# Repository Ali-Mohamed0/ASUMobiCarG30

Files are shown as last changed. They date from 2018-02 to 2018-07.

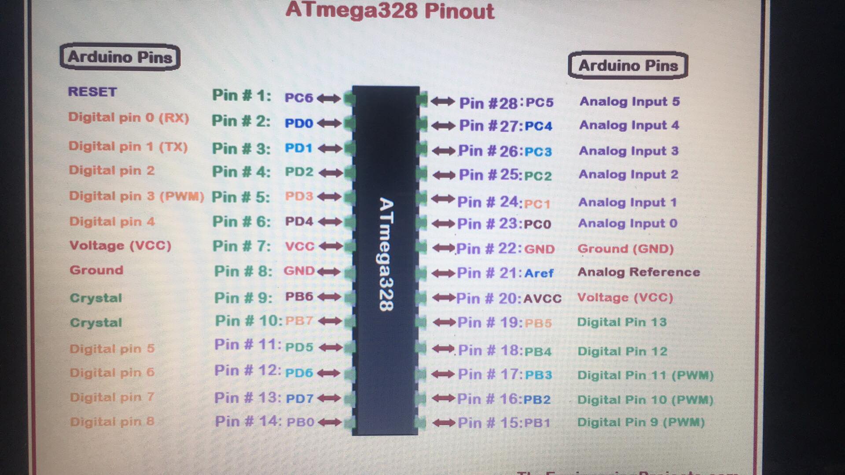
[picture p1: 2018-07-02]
AVR examples & data sheet/AVR pins VS Arduino pins.jpg

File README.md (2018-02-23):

# ASUMobiCarG30
## Smart toy car

smart toy project

This is Project is made by a group of students from Faculty of Engineering AinShams University Electrical engineering department 2nd year Starting by 10/2/2018 till 10/5/2018.

                   Under Supervision of :  Dr Muhammad Sobh

### Smart Car Features Description :

This is an featured RC-Car which have additional skills and options to perform nontraditional missions 

### Easy Driving Application.

  User can control the car Movements Forward ,right..etc, by using an easy mobile app. or by Desktop app. even a 
     child can use it. 
     
  The Car can avoid obstacles under minimum conditions . 

### Line Tracking Application.

   Provide line tracking mode by following a black track on a white background.

### Accurate Movement Application. 

  Provide accurate movement driving mode.
  
  Can move in rectangular shaped path or circle path according to a certain movement distance and angle.
  
### Maximizes the all abilities as possible as can.

  Maximum battery capacity.
  
  Maximum speed.

###  Team Members :                    

#### 1-Ali Mohamed

#### 2-Mayar Gamal

#### 3-Mai Mohsen

#### 4-Ali Ahmed

#### 5-Abdallh Mohamed

#### 6-Sara Krm

#### 7-Omar Abd EL Shafy

#### 8-Mayar Sayed

#### 9-Abdelazim Mohamed

#### 10-Omar Ahmed

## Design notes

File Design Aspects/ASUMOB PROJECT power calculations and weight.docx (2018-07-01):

ASUMOB PROJECT

-This document will show the estimated power calculations ,weight , Expected speed and acceleration of the line follower Robot.

1) Robot Weight:

The estimation of robot weight is between 0.6 kg to 0.8 kg , based on the estimated weight of the chassis and the components :

Note : Fixation weight is included .

-Chassis:

the base of the robot will be a sheet of wood which nearly weighs 0.1 kg .

-Batteries:

6 cells of lithium ion batteries weigh approximately = 0.2 Kg

-Sensors and Pcb :

Approx. 0.2Kg
-motors

2 motors each 0.1 kg

And two tires with 0.08 Kg

2) Torque and power Calculations :

Note: the weight used in all calculations is 0.8 Kg

-Motor power :
we are using two motors each has 250 max RPM and 3 KG.Cm Torque .

Pout “The output power of each motor” = TxW=7.6 Watt

T:torque in N.M

W:angular speed in Rad/sec

-we are targeting a max speed reach in the first second of operation The max speed = RPM x D X Pi /60 =0.9 m/s

D: diameter of the tire

-so the Torque required to achieve 1 m/s acceleration is for each tire calculated by :

T= R x M(For *g+ acc)=0.13 N.M =1.3Kg.cm

For : rolling resistance force , approx. = 0.02 N

M:mass of robot

R:radius of tire

-Since the input power of one motor = IV , also Pin=Pout

Then IV=TW

Using this relation and considering the angular speed is max and the operating voltage is 6 V the current drawn by the motor can be calculated , this is being done as the motor is old and we don’t have a datasheet for it so this is just an estimation

I=TW/V = 0.13x26/6=0.5 Ampere

NOTE : this equation and calculation hasn’t been validated and this is a absolutely an approximation and we are neglecting many factors

As noticed from the equation the relation is linear between the current and the Torque needed ,shown by this graph

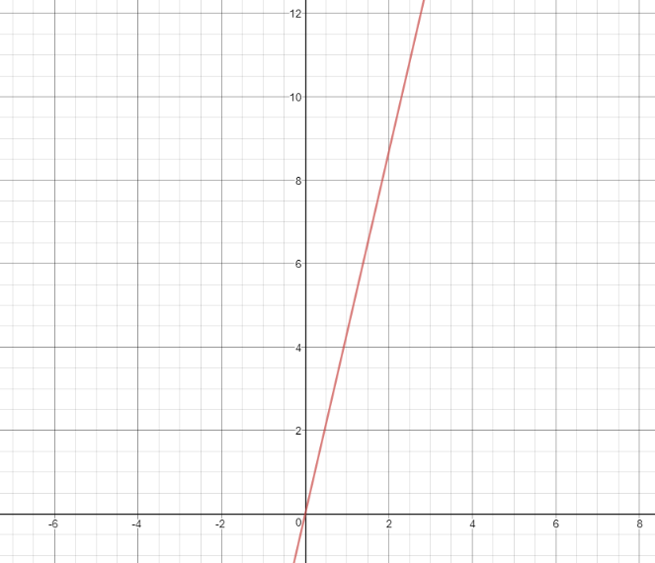
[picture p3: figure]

-Y-axis is I , X-axis is torque

Since Torque = R(For*g+acc) Mass

There is also aan approx. linear relation between Torque and mass , so by substituting in current torque equation ,

I=(WR(For*g+acc) /V)* MASS

The relation is showed by this graph

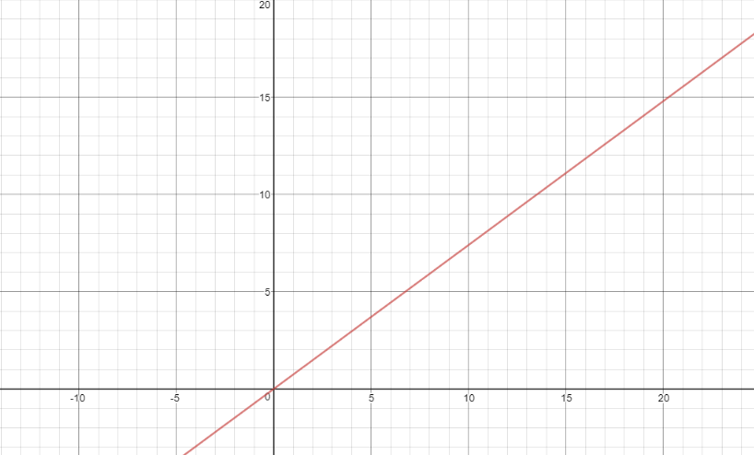
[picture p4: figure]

Y-axis : current

X-axis : mass

By using this graph and relation we can see if adding more batteries will give as advantage or will increase the energy used so we can compromise .

NOTE :this graph and relations has been done manually and not revised or validated this is an approximation which could be wrong .

References :

Graphing calculator :

https://www.desmos.com/calculator

Unit conversions :

-https://www.convertunits.com/from/N-cm/to/kg-cm

-https://www.convertunits.com/from/RPM/to/rad/sec

Equations :

-https://www.physicsforums.com/threads/robot-design-torque-required.512898/

-http://simplemotor.com/calculations/

- https://www.micromo.com/technical-library/dc-motor-tutorials/motor-calculations

- http://www.tribology-abc.com/calculators/cycling.htm

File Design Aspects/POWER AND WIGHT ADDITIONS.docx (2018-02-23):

POWER AND WIGHT ADDITIONS

POWER :

WEIGHT :

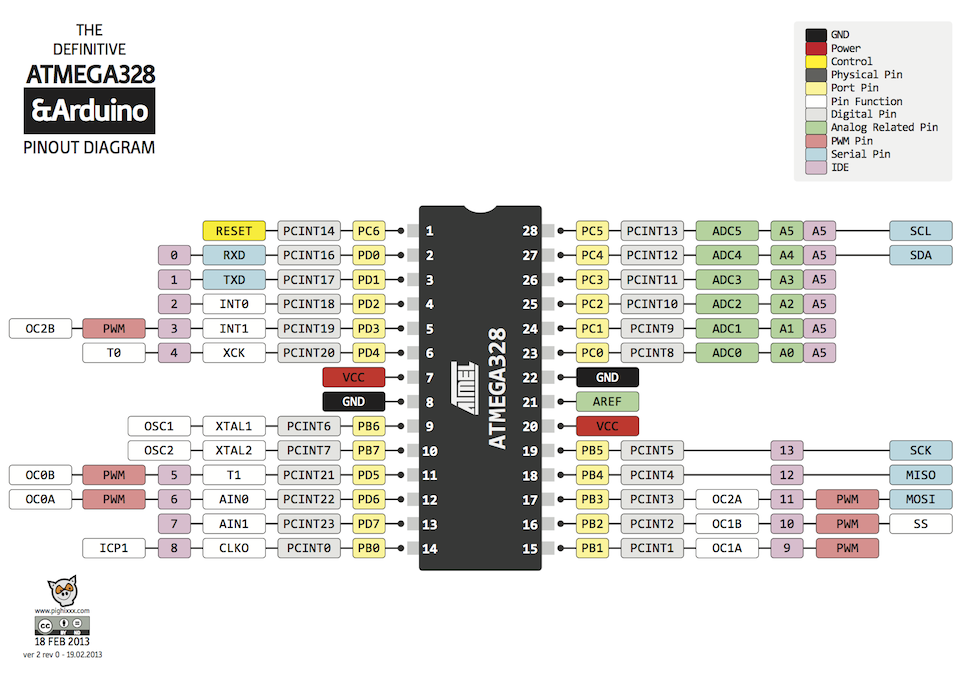
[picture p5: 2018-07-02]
AVR examples & data sheet/ATmega328_pinout_diagram.png

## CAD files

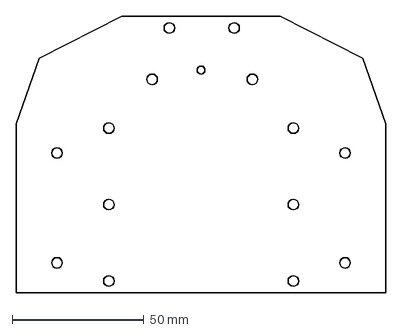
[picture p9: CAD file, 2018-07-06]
Design Simulations/line follower small modified design/final design DXF files/main body.dxf
140.0 x 104.7 mm

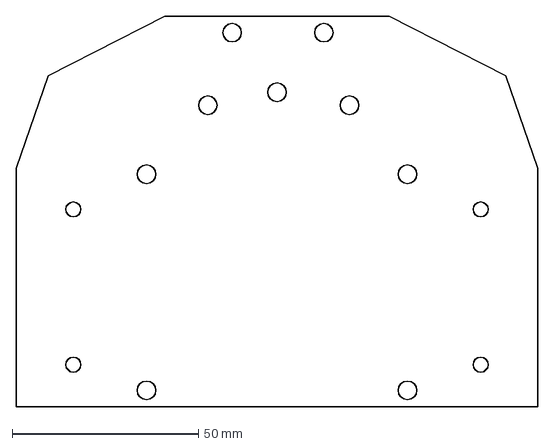
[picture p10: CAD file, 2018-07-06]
Design Simulations/line follower small modified design/final DXF files 5 mm holes/main body.dxf
140.0 x 104.7 mm

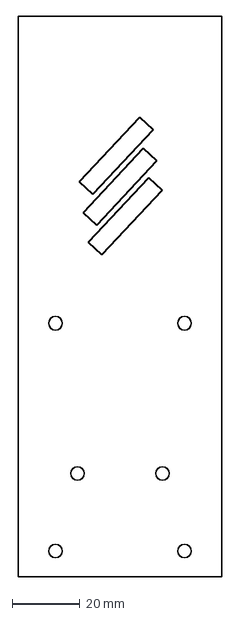
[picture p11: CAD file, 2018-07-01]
Design Simulations/initial design/DXF files/ARM 6mm FINAL with good shape.dxf
60.0 x 165.0 mm

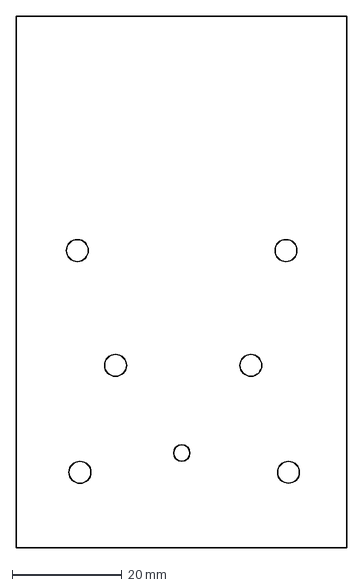
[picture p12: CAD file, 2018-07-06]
Design Simulations/line follower small modified design/final design DXF files/ARM.dxf
60.2 x 96.8 mm

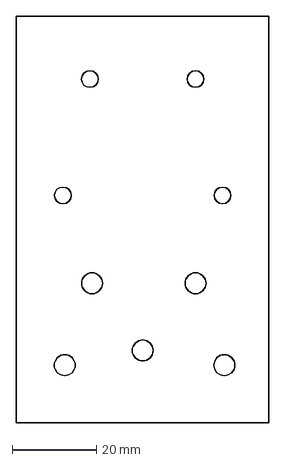
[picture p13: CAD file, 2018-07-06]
Design Simulations/line follower small modified design/final DXF files 5 mm holes/arm.dxf
60.2 x 96.8 mm

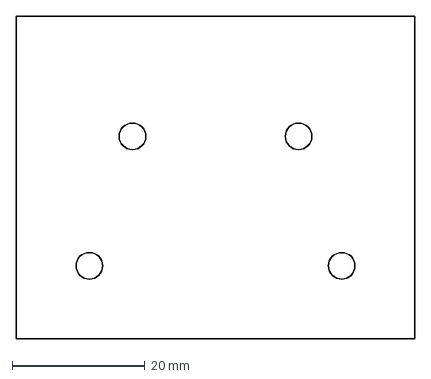
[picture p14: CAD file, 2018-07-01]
Design Simulations/initial design/DXF files/arm support 3mm.dxf
60.0 x 48.5 mm

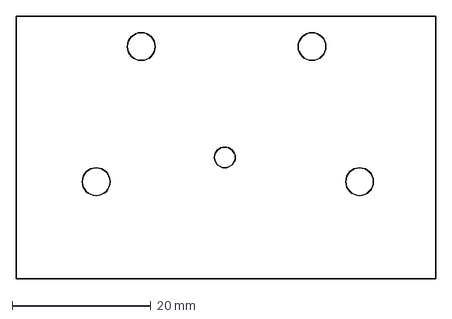
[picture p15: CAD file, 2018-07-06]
Design Simulations/line follower small modified design/final design DXF files/distance supporting part.dxf
60.5 x 37.9 mm

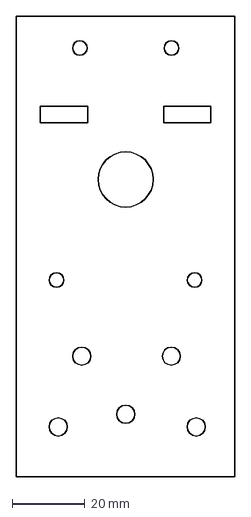
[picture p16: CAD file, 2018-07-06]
Design Simulations/line follower small modified design/final DXF files 5 mm holes/arm final.dxf
60.2 x 126.8 mm

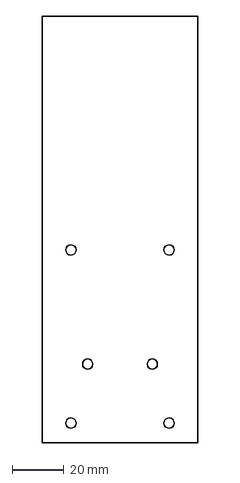
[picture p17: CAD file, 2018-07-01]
Design Simulations/initial design/DXF files/ARM EXTENSION 6 mm FINAL.dxf
60.0 x 165.0 mm

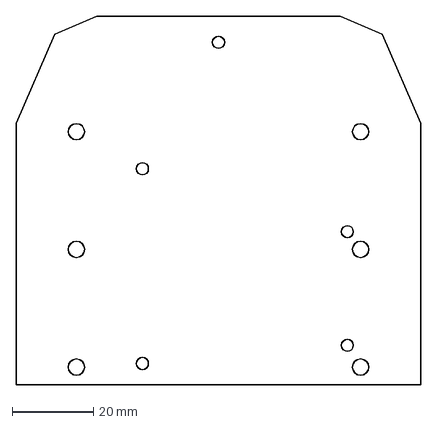
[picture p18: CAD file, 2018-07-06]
Design Simulations/line follower small modified design/final design DXF files/Roof.dxf
99.7 x 90.8 mm

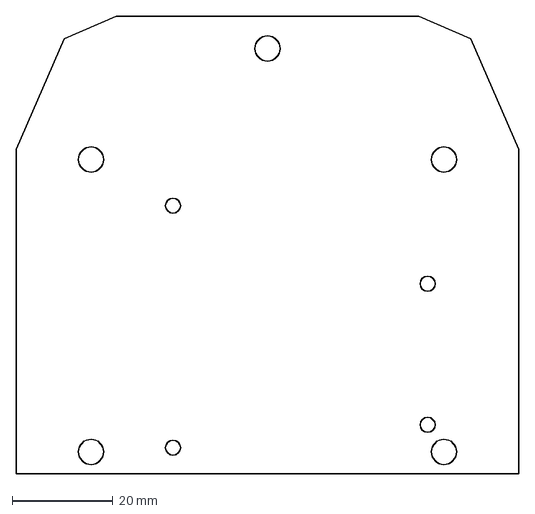
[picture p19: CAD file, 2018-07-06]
Design Simulations/line follower small modified design/final DXF files 5 mm holes/Roof.dxf
99.7 x 90.8 mm

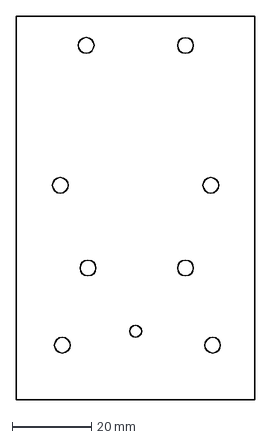
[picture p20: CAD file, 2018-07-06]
Design Simulations/line follower small modified design/final design DXF files/ARM 2.dxf
60.2 x 96.8 mm

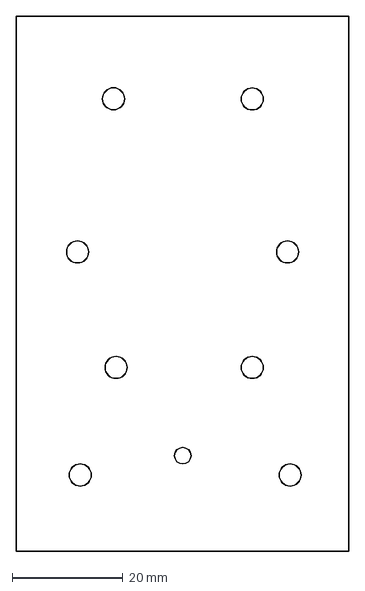
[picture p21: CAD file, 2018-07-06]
Design Simulations/line follower small modified design/final design DXF files/ARM FINAL , WITH IR HOLES.dxf
60.2 x 96.8 mm

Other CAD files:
Design Simulations/initial design/ARM extension 6 mm with drawing.ipt
Design Simulations/initial design/ARM extension 6 mm.ipt
Design Simulations/initial design/car body MAIN PART.ipt
Design Simulations/line follower small modified design/OldVersions/final design with enough battery rooms.0005.ipt
Design Simulations/line follower small modified design/final design with enough battery rooms - Copy.ipt
Design Simulations/line follower small modified design/final design with enough battery rooms.ipt
Design Simulations/line follower small modified design/final design with middle sensor space.ipt
Design Simulations/line follower small modified design/finalll designn small one without arduino boundries.ipt

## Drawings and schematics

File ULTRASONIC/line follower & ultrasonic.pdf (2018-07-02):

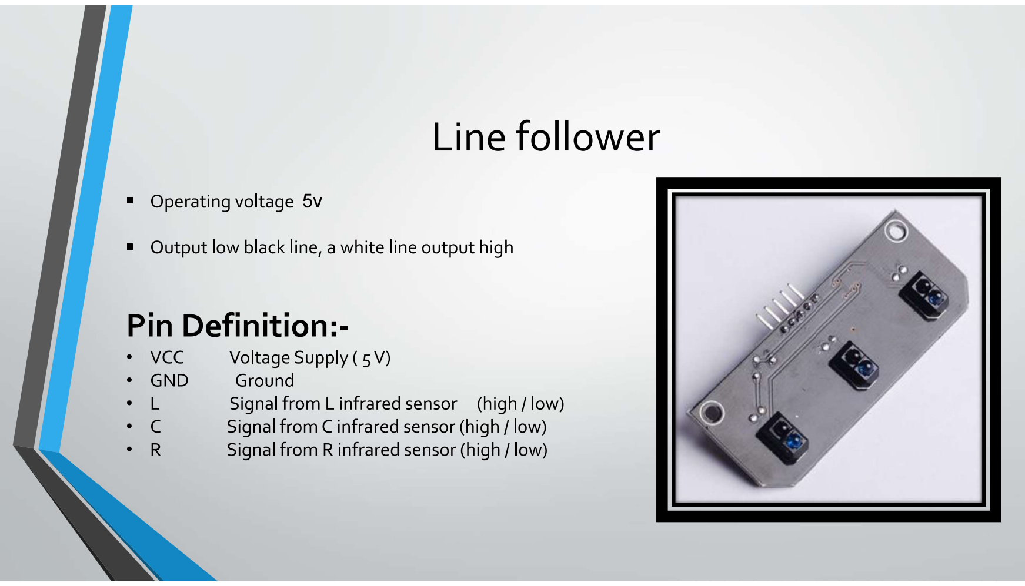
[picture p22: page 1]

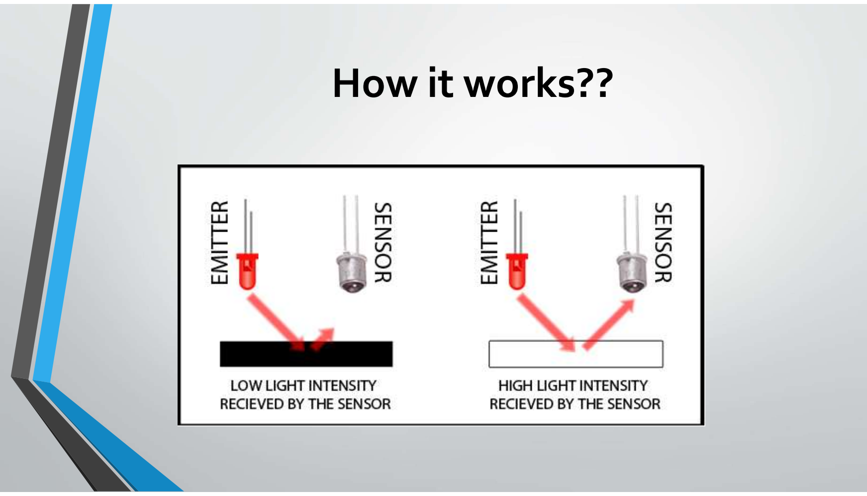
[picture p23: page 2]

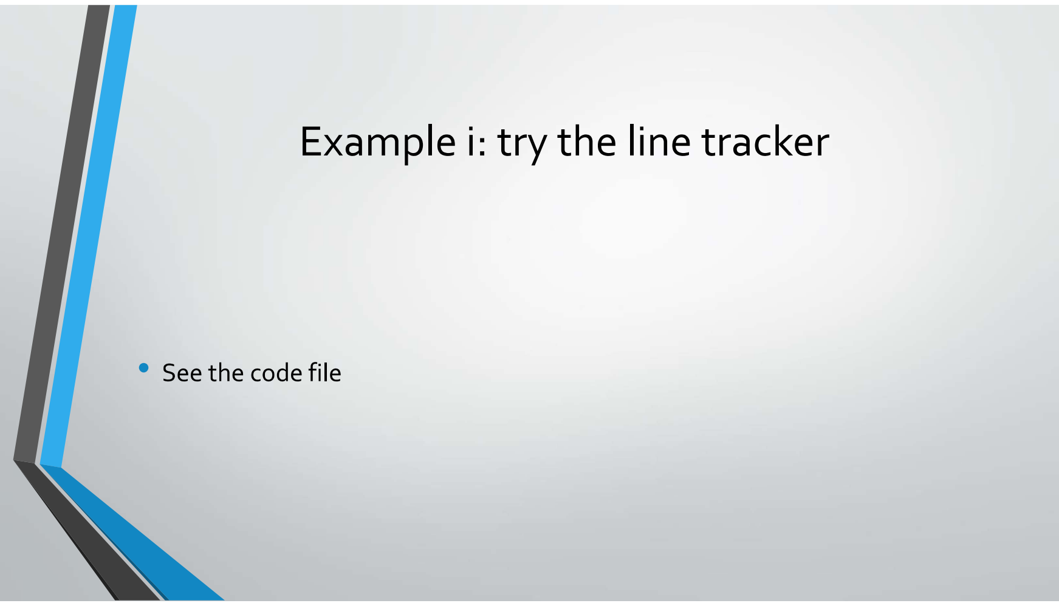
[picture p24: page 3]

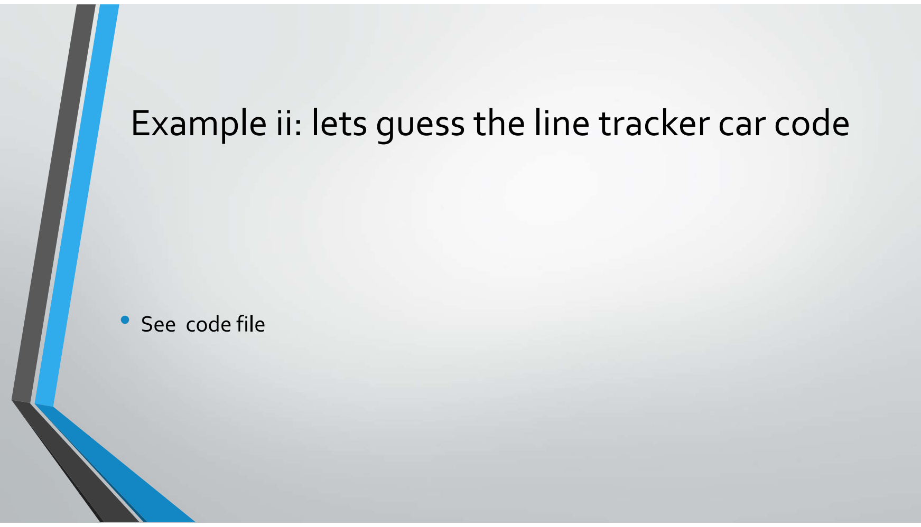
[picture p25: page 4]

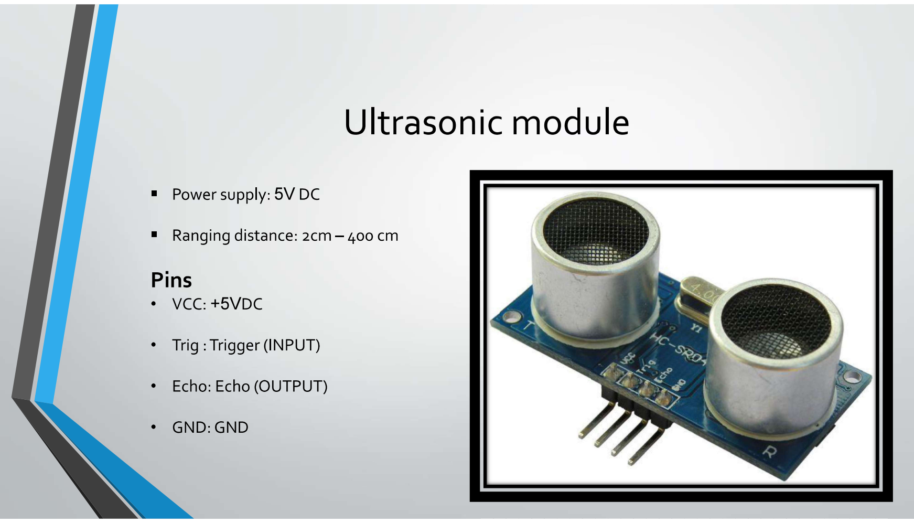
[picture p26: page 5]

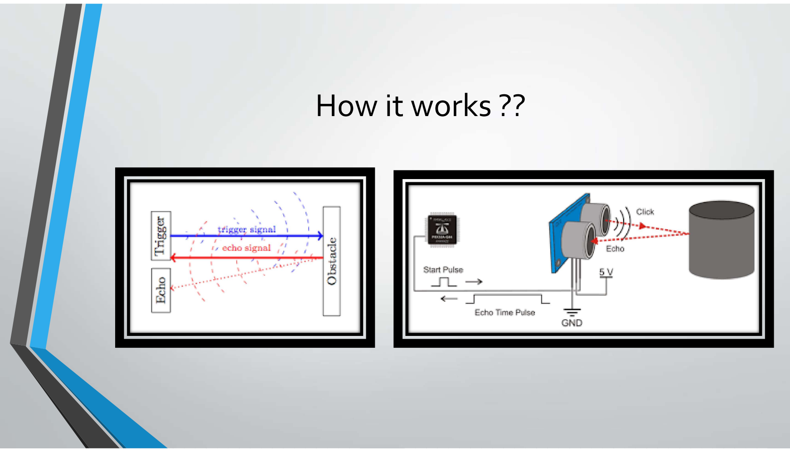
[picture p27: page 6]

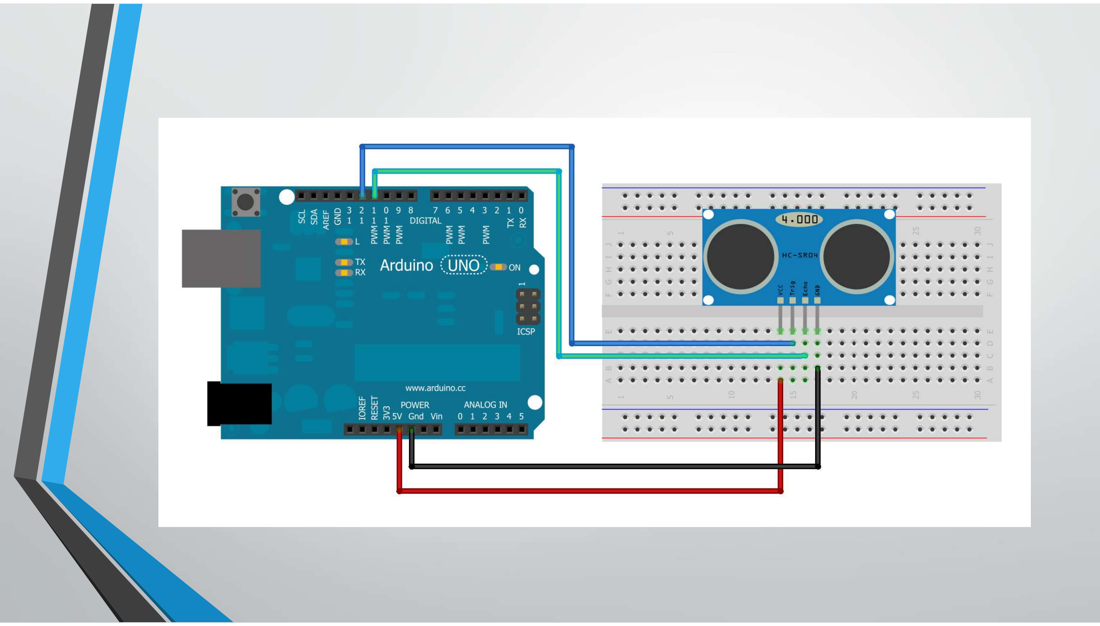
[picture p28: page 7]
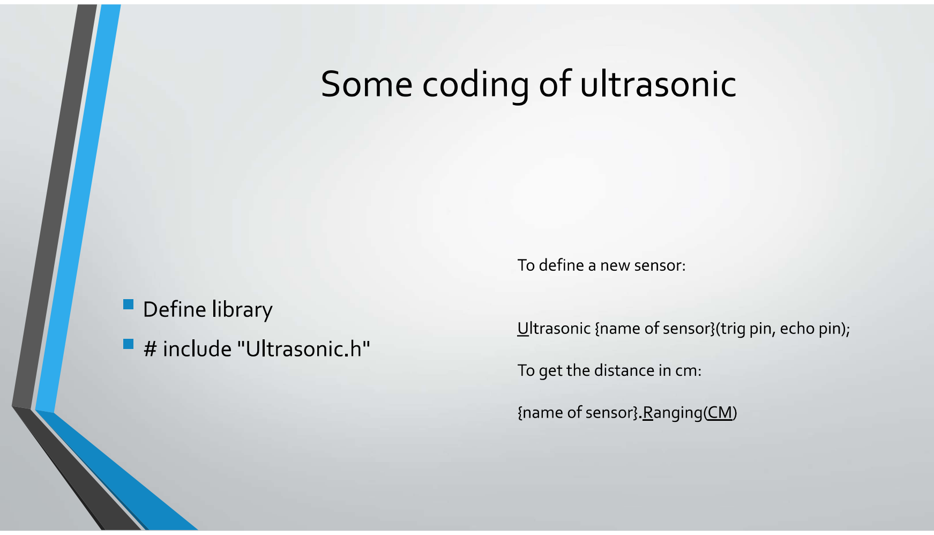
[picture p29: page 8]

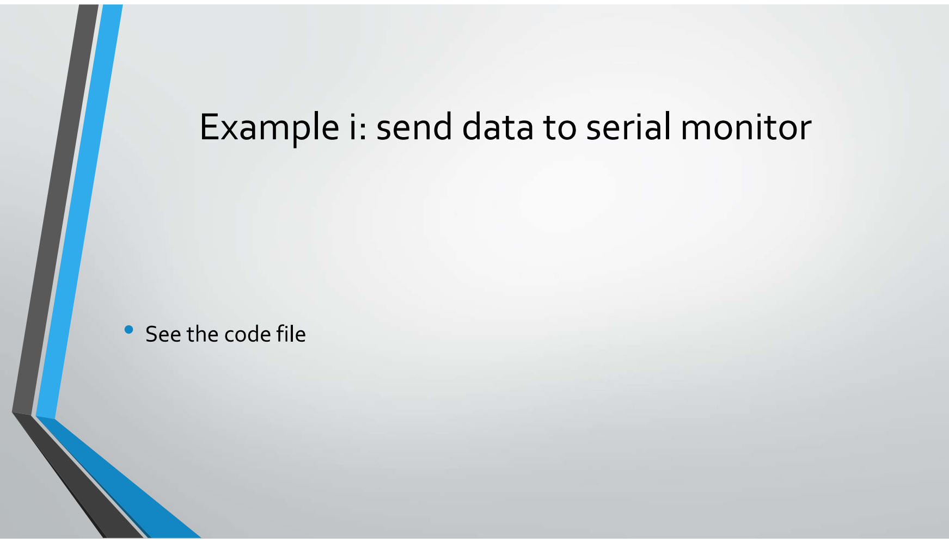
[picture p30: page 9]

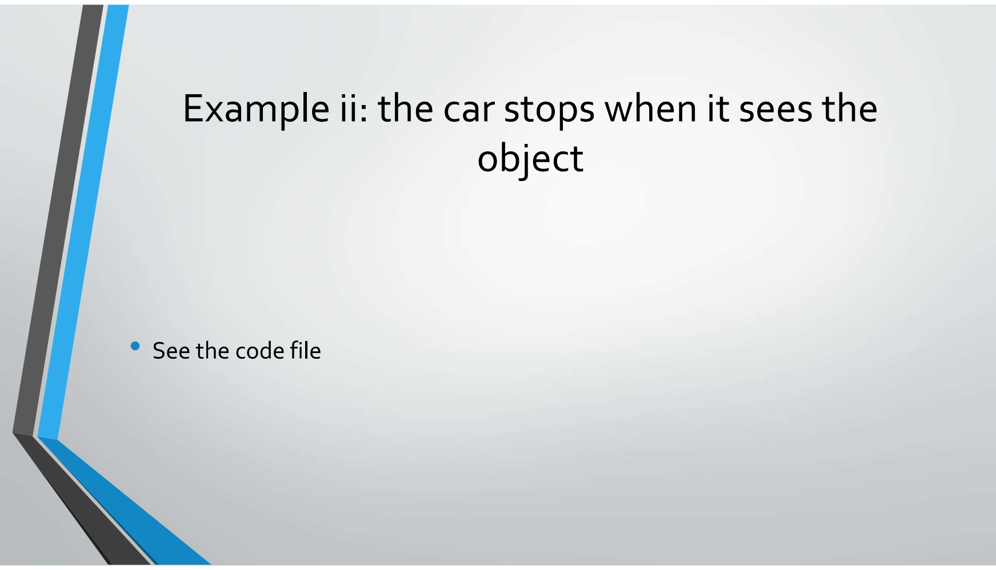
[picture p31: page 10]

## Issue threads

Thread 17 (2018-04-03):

‎problem considering the design frame

Abdallh-Mohamed96, 2018-04-03:

Closed 2018-07-06.

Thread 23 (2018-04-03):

problem solved and design cut

Abdallh-Mohamed96, 2018-04-03:

Abdallh-Mohamed96, 2018-04-21:
modification is in progress

Closed 2018-04-21.

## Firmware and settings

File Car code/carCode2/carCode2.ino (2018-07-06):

int m1f=2;
int m1b=4;
int m1e=5;
int m2f=8;
int m2b=12;
int m2e=6;

int r=0;
int l=0;
int c=1;
int sen3=5;
//line follower
int LeftSen= 3;
int RightSen=13;
int CenterSen= 9 ; 
void forward(int velocity );
void forwardright(int velocity );
void forwardleft(int velocity );
void backward(int velocity);
void right(int velocity);
void left(int velocity);
void stopcar();
void ultrasonic();
void linefollower();
int readLongNum();
void displacement(int dist);
void angle(int ang);
void rect();
void circ();
void inf();
void drawShapes();

//for ultrasonic
const int trigPin = 11;     // defines pins numbers
const int echoPin = 10;
char ultra='u';

int delPercm=60;
int delPerang=10;
float speedratio=2;
int circuleDelay=2500;

char re;
long duration, cm;
long microsecondsToCentimeters(long microseconds)
{
  return microseconds / 29 / 2 ;
}

//........................
int velocity;
void setup() {
  delay(10);
  pinMode(m1f, OUTPUT);
  pinMode(m1b, OUTPUT);
  pinMode(m1e, OUTPUT);
  pinMode(m2f, OUTPUT);
  pinMode(m2b, OUTPUT);
  pinMode(m2e, OUTPUT);

  //line follower
  pinMode(LeftSen,INPUT); 
  pinMode(RightSen,INPUT);
  pinMode(CenterSen,INPUT);
 
  //for Ultrasonic
 pinMode(trigPin, OUTPUT);     // Sets the trigPin as an Output
 pinMode(echoPin, INPUT);     // Sets the echoPin as an Input
 
 Serial.begin(9600);         // Starts the serial communication
}

void loop() {
  delay(50);
  if(Serial.available()){
      re=Serial.read();  

  if ( re == '1' ){
    velocity = 0;
  }else if ( re == '2' ){
    velocity = 100;
  }else if (re == '3' ){
    velocity = 200;
  }else if (re == '4' ){
    velocity = 254;
  }


 
    }
    if(re=='F'){forward( velocity);}
    if(re=='B'){backward( velocity);}
    if(re=='R'){right( velocity);}
    if(re=='L'){left( velocity); }
    if(re=='S'){stopcar();}
    if(re=='A'){linefollower();}
    if(re=='U'){ultra='U';}
    if(re=='u'){ultra='u';}
    if(re=='D'){displacement(readLongNum());re='e';}
    if(re=='G'){angle(readLongNum());re='e';}
    if(re=='T'){velocity=readLongNum();re='e';}
    if(re=='d'){delPercm=readLongNum();re='e';}
    if(re=='a'){delPerang=readLongNum();re='e';}
    if(re=='r'){speedratio=readLongNum()/100.0;re='e';}
    if(re=='c'){circuleDelay=readLongNum();re='e';}
    if(re=='h'){drawShapes();re='e';}
    if(re=='o'){rect();re='e';}
    if(re=='p'){circ();re='e';}
    if(re=='q'){inf();re='e';}
    //Serial.println(speedratio);
    if(ultra=='U'){
      ultrasonic();
    }
    
          
}
/*line folower*/
 void linefollower(){ 
  r=digitalRead(RightSen);
  c=digitalRead(CenterSen);
  l=digitalRead(LeftSen);
  
  if (!l & c & !r)
  {
    forward(velocity);
  }

  else if(!l & !c & r )
  {
    right(velocity);
  }
  else if(l & !c & !r)
  {
    left(velocity);
  }
 
} 

  /*****************************/
void ultrasonic(){
  delay(100);
  digitalWrite(trigPin, LOW);       // Clears the trigPin
  delayMicroseconds(2);
  digitalWrite(trigPin, HIGH);       // Sets the trigPin on HIGH state for 10 micro seconds
  delayMicroseconds(10);
  digitalWrite(trigPin, LOW);

  duration = pulseIn(echoPin, HIGH);    // Reads the echoPin, returns the sound wave travel time in microseconds
 
   cm = microsecondsToCentimeters(duration);
  //Serial.print(cm);
  //Serial.print("cm");
               

     if(cm<30) 
  {
    stopcar();
    delay(1000);
    backward(velocity);
    delay(500);
    left(velocity);   // turn left
    delay(700);
    stopcar();
  }
  
  } 

void forward(int velocity){
    
  analogWrite(m1e, velocity);
  analogWrite(m2e, velocity);
  digitalWrite(m1f, HIGH);
  digitalWrite(m2f, HIGH);
  digitalWrite(m1b, LOW);
  digitalWrite(m2b, LOW);
  }
  void forwardright(int velocity ){
  analogWrite(m1e, velocity*speedratio);
  analogWrite(m2e, velocity);
  digitalWrite(m1f, HIGH);
  digitalWrite(m2f, HIGH);
  digitalWrite(m1b, LOW);
  digitalWrite(m2b, LOW);
  }
void forwardleft(int velocity ){
   analogWrite(m1e, velocity);
  analogWrite(m2e, velocity*speedratio);
  digitalWrite(m1f, HIGH);
  digitalWrite(m2f, HIGH);
  digitalWrite(m1b, LOW);
  digitalWrite(m2b, LOW);
}
void backward(int velocity){
  analogWrite(m1e, velocity);
  analogWrite(m2e, velocity);
  digitalWrite(m1f, LOW);
  digitalWrite(m2f, LOW);
  digitalWrite(m1b, HIGH);
  digitalWrite(m2b, HIGH);
  
  }

  
void right(int velocity){
  analogWrite(m1e, velocity);
  analogWrite(m2e, velocity);
  digitalWrite(m1f, LOW);
  digitalWrite(m2f, HIGH);
  digitalWrite(m1b, LOW);
  digitalWrite(m2b, LOW);
  }
  
void left(int velocity){
  analogWrite(m1e, velocity);
  analogWrite(m2e, velocity);
  digitalWrite(m1f, HIGH);
  digitalWrite(m2f, LOW);
  digitalWrite(m1b, LOW);
  digitalWrite(m2b, LOW);
  }
  
void stopcar(){
  analogWrite(m1e, velocity);
  analogWrite(m2e, velocity);
  digitalWrite(m1f, LOW);
  digitalWrite(m2f, LOW);
  digitalWrite(m1b, LOW);
  digitalWrite(m2b, LOW);  
  }

  int readLongNum(){
  int NumLen;
  int tempNum;
  int rightNum=0;
  int i;
  int sflag=1;
 
  while(1){
    if(Serial.available()){
      if(sflag==1){
        NumLen=Serial.read();
        i=NumLen-'0';
        sflag=0;
      }else{
        tempNum=Serial.read();
        i--;
      
        if(tempNum=='q')break;
        else {
          tempNum=tempNum - '0';
          rightNum+=tempNum*pow(10,i);
        }
      }
    }
  }

return rightNum;
  
}
void displacement(int dist){
  forward( velocity);
  delay(dist*delPercm);
  stopcar();
}
void angle(int ang){
  left(velocity);
  delay(ang*delPerang);
  stopcar();
}
void rect(){
  displacement(100);
  angle(90);
  displacement(100);
  angle(90);
  displacement(100);
  angle(90);
  displacement(100);
  angle(90);
}
void circ(){
  forwardleft(velocity);
  delay(circuleDelay);
  stopcar();
}
void inf(){
   forwardleft(velocity);
  delay(circuleDelay);
  forwardright(velocity);
  delay(circuleDelay);
  stopcar();
}
void drawShapes(){
  rect();
  delay(10000);
  circ();
  delay(10000);
  inf();
}

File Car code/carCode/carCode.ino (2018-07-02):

#include <avr/io.h>
#include <util/delay.h>
int sen1=3;
int sen2=7;
int sen3=5;
int LeftSen= 1;
int RightSen=1;
int Center= 1 ;
void forward(int velocity );
void backward(int velocity);
void right(int velocity);
void left(int velocity);
void stopcar();
void inc_speed();
void dec_speed();
void ultrasonic();
void linefollower();

//for ultrasonic
const int trigPin = 11;     // defines pins numbers
const int echoPin = 10;
const int vcc = 7 ;
char re;
long duration, cm;
long microsecondsToCentimeters(long microseconds)
{
  return microseconds / 29 / 2 ;
}

//........................
int velocity;
void setup() {
  DDRB |= 1 << PINB1;  //setting B1 as an output
  DDRD |= 1 << PIND2;  //setting D2 as an output
  DDRD |= 1 << PIND4;  //setting D4 as an output
  DDRD |= 1 << PIND6;  //setting D6 as an output
  DDRB |= 1 << PINB0;  // setting B0 as an output
  DDRB |= 1 << PINB4;  // setting B4 as an output

  //line follower
    pinMode(sen1,INPUT); 
   pinMode(sen2,INPUT);
     pinMode(sen3,INPUT);
   /*..............*/

  //---setting fast pwm mode bits on TC0 Control Register A ---// 
    TCCR0A |=1<<COM0A1 ;
    TCCR0A |=1<<WGM00 ;
    TCCR0A |=1<<WGM01 ;
    //--------------------------------------------//
    
   //---setting fast pwm mode bits on TC0 Control Register B ---//
      TCCR0B |=1<<CS00 ; //no prescalling
    //-----------------------------------------------------------// 

        //---setting fast pwm mode bits on TC1 Control Register A ---// 
    TCCR1A |=1<<COM1A1 ;
    TCCR1A |=1<<WGM10 ;
    TCCR1B |=1<<WGM12 ;
    //--------------------------------------------//


   //---setting fast pwm mode bits on TC1 Control Register B ---//
      TCCR1B |=1<<CS10 ; //no prescalling
    //-----------------------------------------------------------// 
  
  //for Ultrasonic
 pinMode(trigPin, OUTPUT);     // Sets the trigPin as an Output
 pinMode(echoPin, INPUT);     // Sets the echoPin as an Input
 
 Serial.begin(9600);         // Starts the serial communication
}

void loop() {
  if(Serial.available()){
      re=Serial.read();  

  if ( re == '1' ){
    velocity = 0;
  }else if ( re == '2' ){
    velocity = 100;
  }else if (re == '3' ){
    velocity = 200;
  }else if (re == '4' ){
    velocity = 255;
  }


 
    }
    if(re=='F'){forward( velocity);}
    if(re=='B'){backward( velocity);}
    if(re=='R'){right( velocity);delay (500); stopcar();}
    if(re=='L'){left( velocity); delay (500); stopcar(); }
    if(re=='S'){stopcar();}
    if(re=='A'){linefollower();}
    
    Serial.println(re);
   // ultrasonic();
          
}
/*line folower*/
void linefollower(){ 
  RightSen=digitalRead(sen1);
  Center=digitalRead(sen3);
  LeftSen=digitalRead(sen2);
  
  if ((RightSen==HIGH & LeftSen==HIGH)| Center==HIGH)
  {
    forward(velocity);
  }

  else if((RightSen==HIGH & LeftSen==LOW & Center==LOW)|( RightSen==HIGH & LeftSen==LOW & Center==HIGH))
  {
    right(velocity);
  }
  else if((RightSen==LOW & LeftSen==HIGH &  Center==HIGH)|( RightSen==LOW & LeftSen==HIGH & Center==LOW))
  {
    left(velocity);
  }
 
}

  /*****************************/
/*void ultrasonic(){
  digitalWrite(trigPin, LOW);       // Clears the trigPin
  delayMicroseconds(2);
  digitalWrite(trigPin, HIGH);       // Sets the trigPin on HIGH state for 10 micro seconds
  delayMicroseconds(10);
  digitalWrite(trigPin, LOW);

  duration = pulseIn(echoPin, HIGH);    // Reads the echoPin, returns the sound wave travel time in microseconds
 
   cm = microsecondsToCentimeters(duration);
  //Serial.print(cm);
  //Serial.print("cm");
               

     if(cm<30) 
  {
    stopcar();
    delay(1000);
    backward(velocity);
    delay(500);
    left(velocity);   // turn left
    delay(400);
    stopcar();
  }
  
  } */

void forward(int velocity){
  OCR0A = velocity ;
  OCR1A = velocity ;  
  PORTD &= 0 << PIND4 ; //M1B LOW
  PORTB &= 0 << PINB4 ; //M2B LOW
  PORTD |= 1 << PIND2 ; //M1F high 
  PORTB |= 1 << PINB0 ; //M2F high 
  Serial.println(re);
  }
  
void backward(int velocity){
  OCR0A = velocity ;
  OCR1A = velocity ;
  PORTD &= 0 << PIND2 ; //M1F low
  PORTB &= 0 << PINB0 ; //M2F low
  PORTD |= 1 << PIND4 ; //M1B high
  PORTB |= 1 << PINB4 ; //M2B high
  
  }

  
void right(int velocity){
  OCR0A = velocity ;
  OCR1A = velocity ;
  PORTD |= 1 << PIND4 ; //M1B high
  PORTB &= 0 << PINB4 ; //M2B low
  PORTD &= 0 << PIND2 ; //M1F LOW 
  PORTB |= 1 << PINB0 ; //M2F high 
  }
  
void left(int velocity){
  OCR0A = velocity ;
  OCR1A = velocity ;
  PORTD &= 0 << PIND4 ; //M1B low
  PORTB |= 1 << PINB4 ; //M2B high
  PORTD |= 1 << PIND2 ; //M1F high 
  PORTB &= 0 << PINB0 ; //M2F low 
  }
  
void stopcar(){
  OCR0A = velocity ;
  OCR1A = velocity ;
  PORTD &= 0 << PIND4 ; //M1B low
  PORTB &= 0 << PINB4 ; //M2B low
  PORTD &= 0 << PIND2 ; //M1F low 
  PORTB &= 0 << PINB0 ; //M2F low   
  }
  
  
/*void inc_speed(){
  
  OCR0A +=50; 
  OCR0B +=50; 
  
  if (OCR0A > 255){
      OCR0A = 255 ; 
      }
  }


 
void dec_speed(){
  OCR0A -=50; 
  OCR1A -=50;
  OCR0B -=50; 
  OCR1B -=50;
  
   if (OCR0A < 0 ){
     OCR0A = 0 ; 
      } 
  }  */

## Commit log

2018-02-18 add first arduino example
2018-02-23 Power and Weight Calculations
2018-02-24 connection
    removed the previous connection as it can be done from the mobile and establish directly a thread to connect to communicate via bluetooth socket and added the permissions
2018-02-24 accept thread class , thread note
    the accpet thread class is for accpting msgs from other paired devices and in our case we dont need it
2018-02-24 Create ULTRASONIC
2018-02-25 Update blinking led
2018-02-26 VERSION 2
    IT Contains pairing and discovering bluetooth devices
2018-02-26 ULTRASONIC
    basics and examples of ultrasonic
2018-02-26 code doesn't work & i don't know why :(
    [light_intenisty.ino]
2018-02-27 start connection button and bluetooth service class
2018-03-02 remove interrupt
2018-04-01 the end of it :D
    added background and some colors and the speeds buttons
2018-07-01 intial design
    [ARM 6mm FINAL with good shape.dxf, ARM EXTENSION 6 mm FINAL.dxf, ARM extension 6 mm with drawing.ipt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]
2018-07-01 initial design
    [ARM 6mm FINAL with good shape.dxf, ARM EXTENSION 6 mm FINAL.dxf, ARM extension 6 mm with drawing.ipt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]
2018-07-03 Moving from Avr to arduino
2018-07-03 solw Ultrasonic
2018-07-04 design modified to enhance performance on line follower track
    [final design with enough battery rooms - Copy.ipt, final design with enough battery rooms.0005.ipt, final design with enough battery rooms.ipt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]
2018-07-04 battries space
    more space were added to carry twice the battries
    [final modified design with no sensor space.ipt]
2018-07-04 New design DXF files
    DXF modified files has been made for laser cutting also roof screws holes has been changed from 4 to 5 mm
    [Roof.dxf, arm final.dxf, arm.dxf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]
2018-07-04 final DXF files with all modifications
    [ARM 2.dxf, ARM FINAL , WITH IR HOLES.dxf, ARM.dxf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]
